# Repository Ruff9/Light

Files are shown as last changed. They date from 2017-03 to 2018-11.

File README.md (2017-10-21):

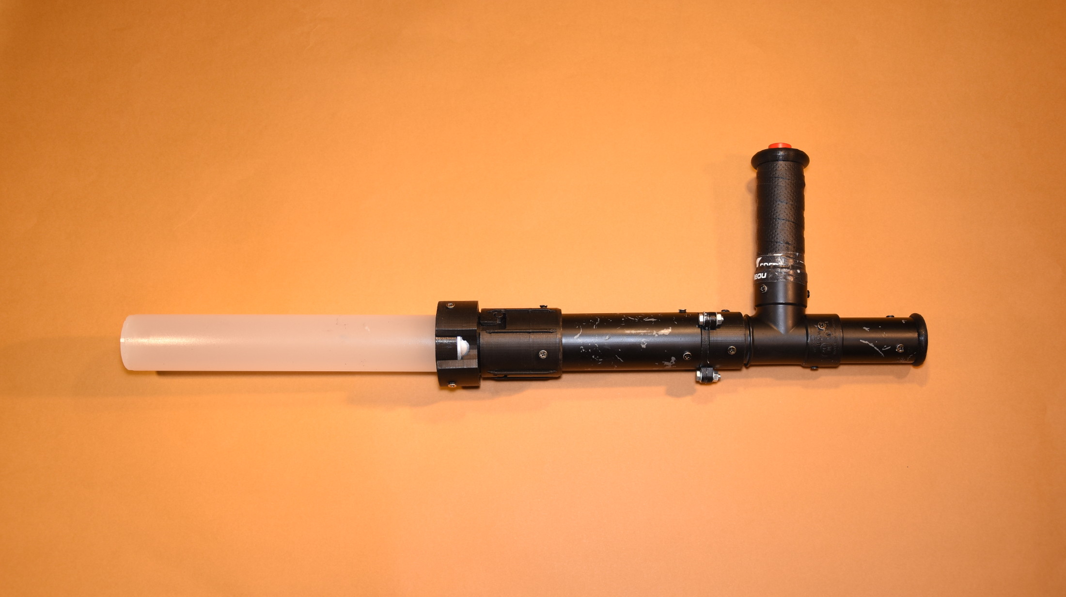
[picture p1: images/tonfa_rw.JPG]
tonfa


# Light Tonfa

Projet réalisé avec [OpenScad](http://www.openscad.org/) au FabLab du [Carrefour Numérique](http://carrefour-numerique.cite-sciences.fr/fablab/wiki/doku.php?_ga=1.200240622.1982442383.1430227391).

Ce repo contient les fichiers originaux openscad et les fichiers .stl prêts pour être chargés dans un slicer.

## Temps d'impression

Durées indicatives, correspondantes aux réglages choisis pour une Ultimaker 2. Chaque tonfa aura nécessité 32h d'impression et 1h30 d'assemblage.

- interieur: 3h
- cale_interieur: 20min
- reducteur_a: 5h30
- reducteur_b: 2h30
- embout: 2h40
- pommeau: 4h30
- cale_ampoule: 1h30
- contact_reducteur: 15min
- douille: 6h
- culot: 5h40
- ressort: 30min

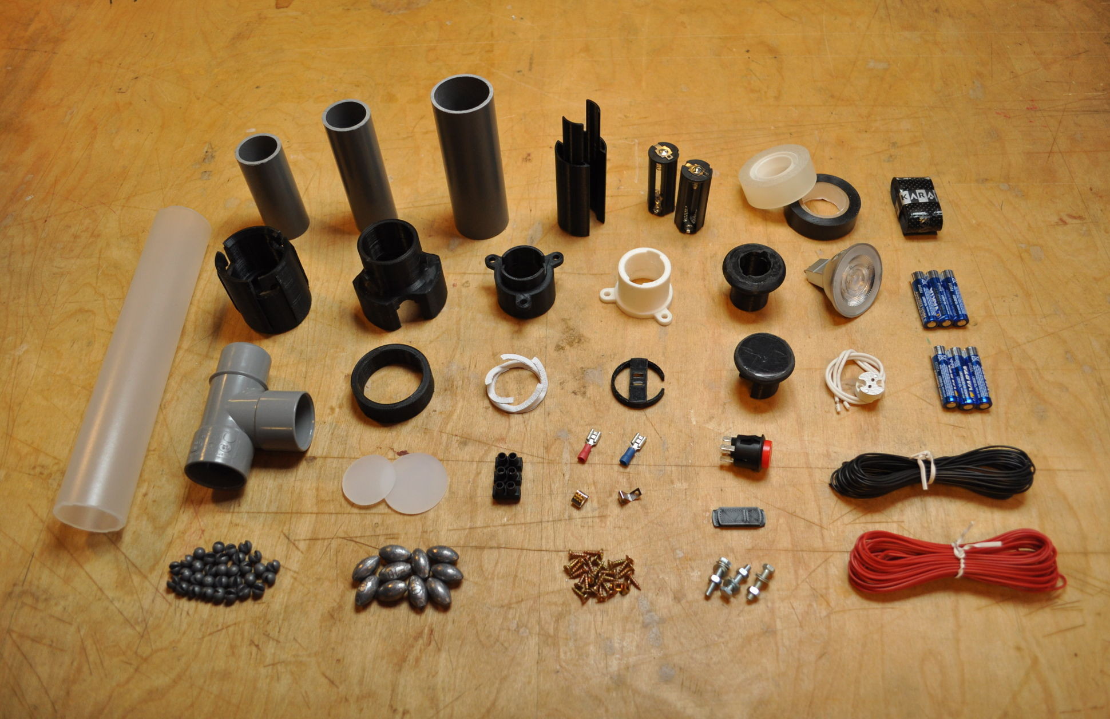
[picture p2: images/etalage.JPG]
etalage


## Autres pièces nécessaires

Tubes PVC plomberie:

- Diamètre 40mm, longueur 115 mm
- Diamètre 32mm, longueur 75mm
- Diamètre 32mm, longueur 100mm

Tube PVC translucide:

- Diamètre 40mm, longueur 230mm

Electronique

- Bouton poussoir
- 2 cosses
- 2 contacteurs
- 2 supports pour 3 piles AAA
- Domino
- Câbles

Autres:

- Raccord de plomberie en T diamètre 32mm
- Spot d'ameublement + connectique
- Rondelle de PVC translucide, diamètre 40mm
- 6 piles AAA
- 165 grammes de plombs de peche
- Sur-grip de raquette de tennis
- 24 vis de menuiserie, diamètre 4mm
- 6 écrous + vis
- Bombe de peinture noire

## Machines / outils

- Imprimante 3D
- Micro-ponçeuse (Dremel)
- Fer à souder + étain
- Banc de scie
- Perçeuse + forêt de 3.5 mm
- Visseuse
- Découpe laser (rondelle de plexiglas)
- Tournevis
- 2 Clés plates de 7

## Todo

Notice d'assemblage, wiki

## Licence

Ces fichiers sont distribués sous la licence [Creative Commons Attribution-Partage 3.0](https://creativecommons.org/licenses/by-sa/3.0/fr/).

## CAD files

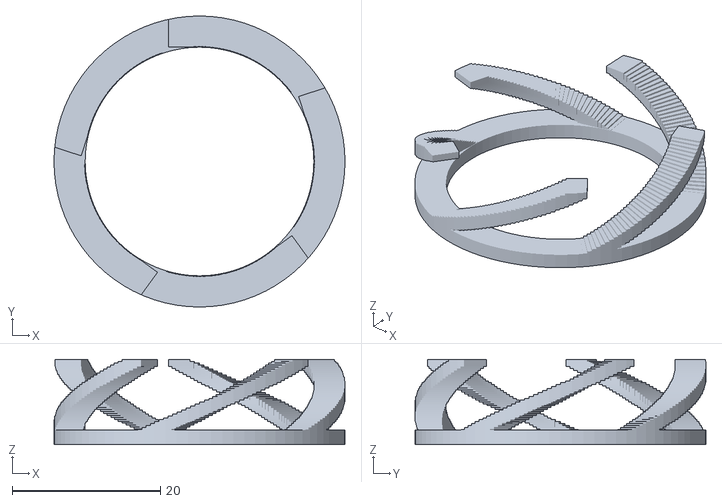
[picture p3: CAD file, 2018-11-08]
stl/ressort.stl
39.2 x 39.2 x 11.5

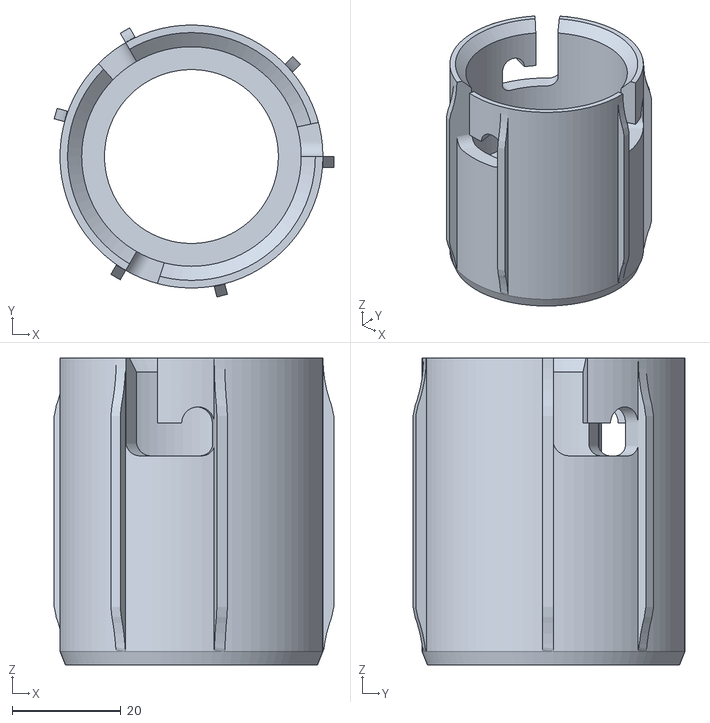
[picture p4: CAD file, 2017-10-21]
stl/douille.stl
51.5 x 50.1 x 56.5

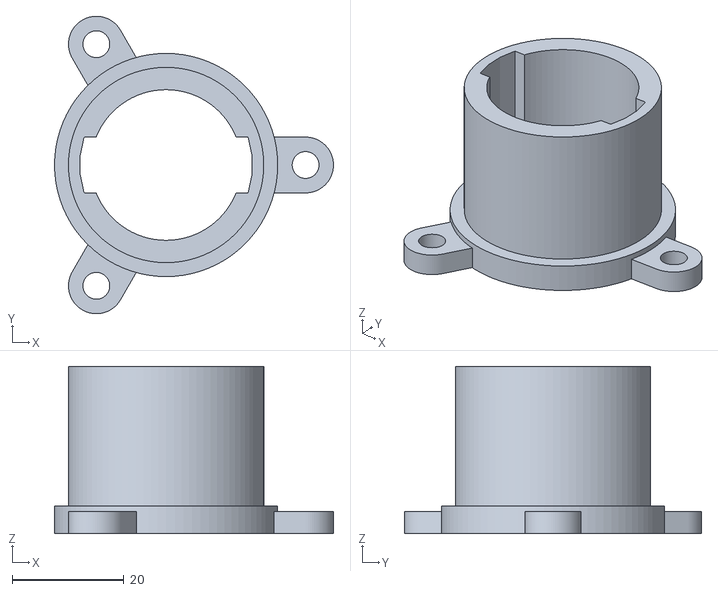
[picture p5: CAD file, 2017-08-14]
stl/reducteur_B.stl
50.0 x 53.3 x 30.0

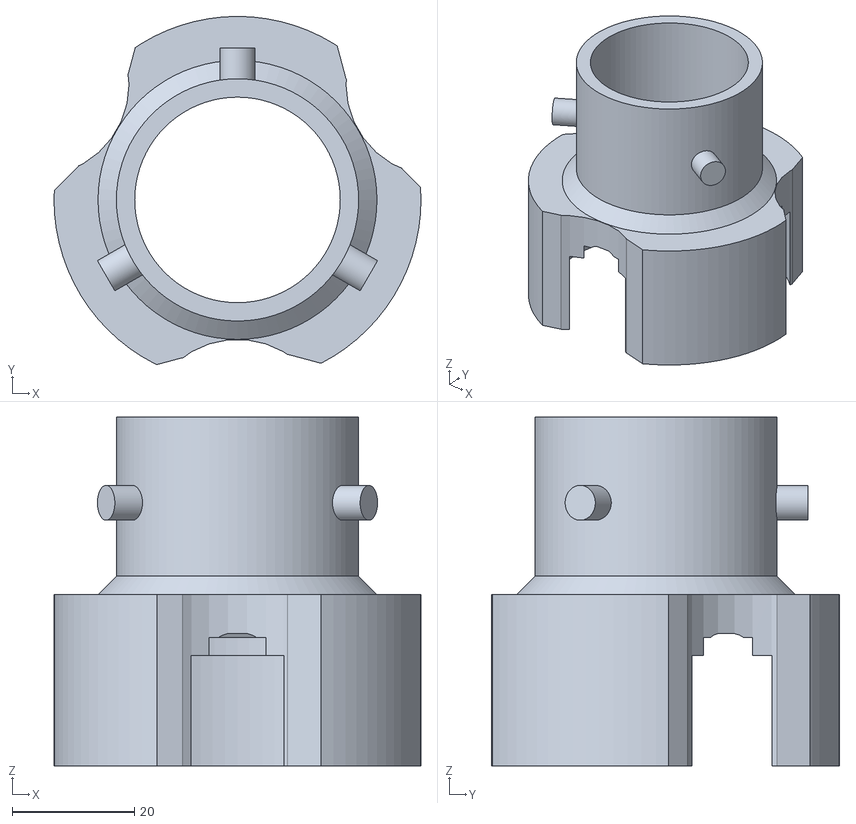
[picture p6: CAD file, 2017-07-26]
stl/culot.stl
60.0 x 56.9 x 57.0

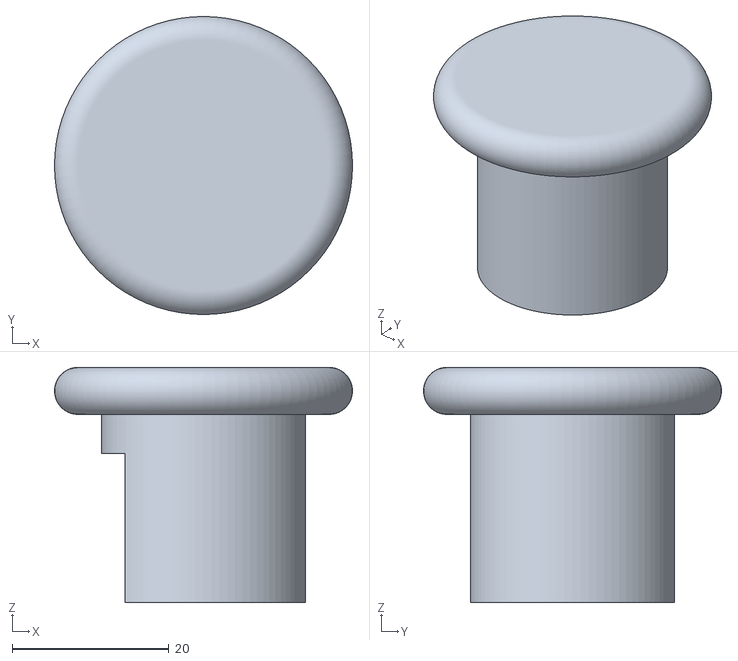
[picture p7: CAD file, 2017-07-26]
stl/embout.stl
38.0 x 38.0 x 30.0

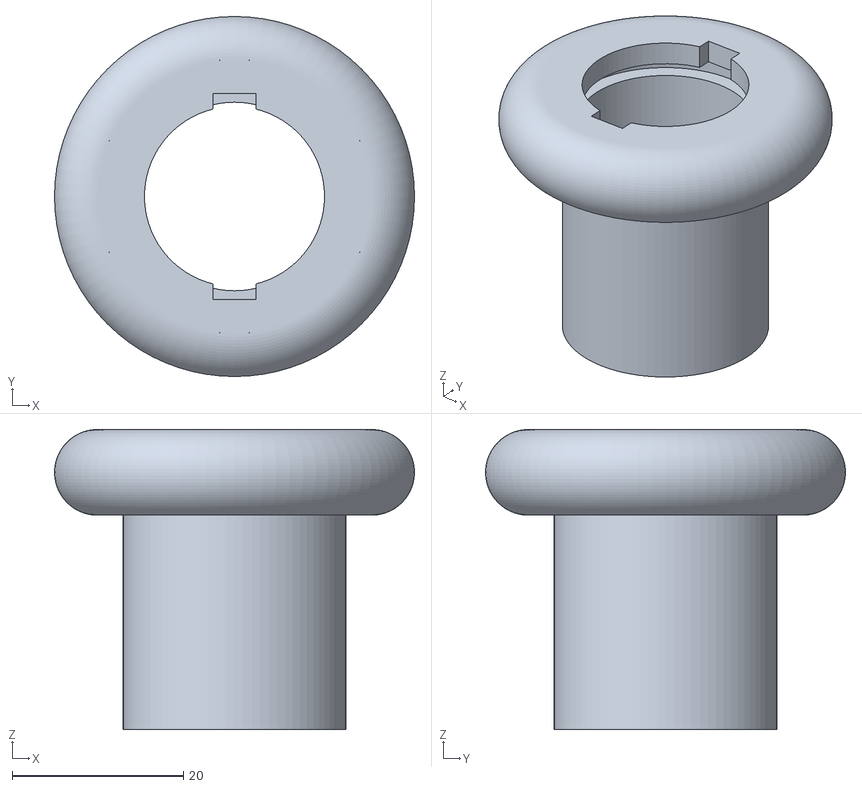
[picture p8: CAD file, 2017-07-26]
stl/pommeau.stl
42.0 x 42.0 x 35.0

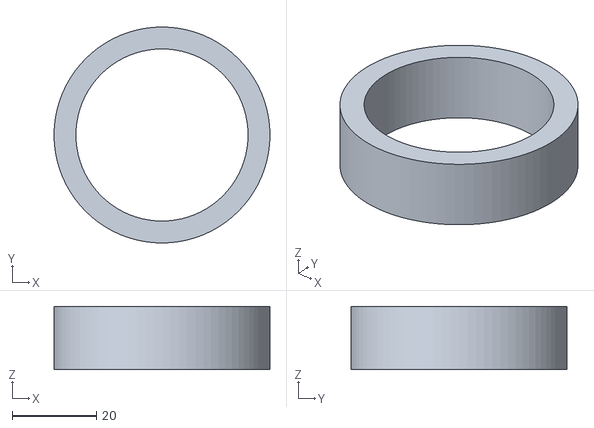
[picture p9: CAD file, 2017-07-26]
stl/cale_ampoule.stl
51.2 x 51.2 x 15.0

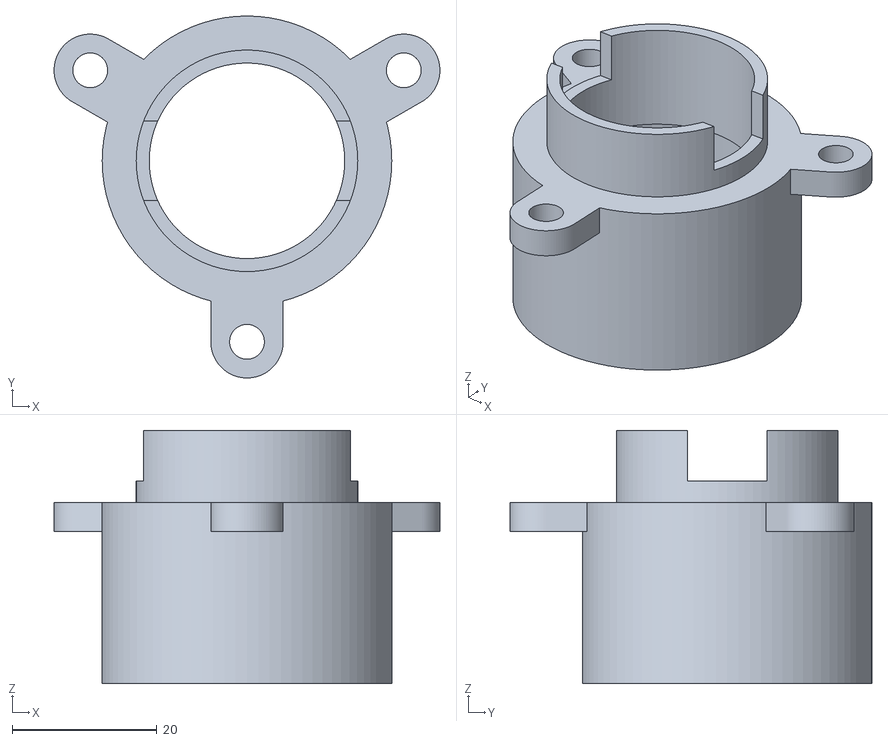
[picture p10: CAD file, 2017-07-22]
stl/reducteur_A.stl
53.3 x 50.0 x 35.0

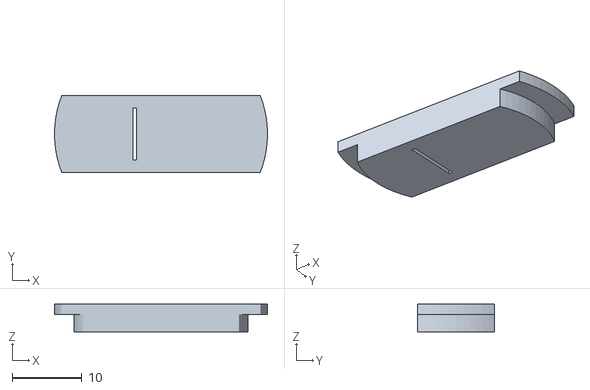
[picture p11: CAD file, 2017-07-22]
stl/contact_reducteur.stl
30.6 x 11.0 x 4.00

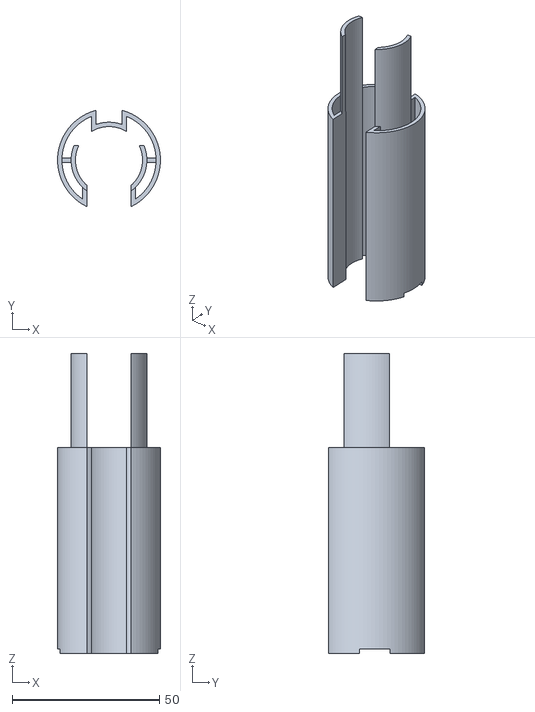
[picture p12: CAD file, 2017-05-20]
stl/interieur.stl
35.0 x 32.7 x 102.0

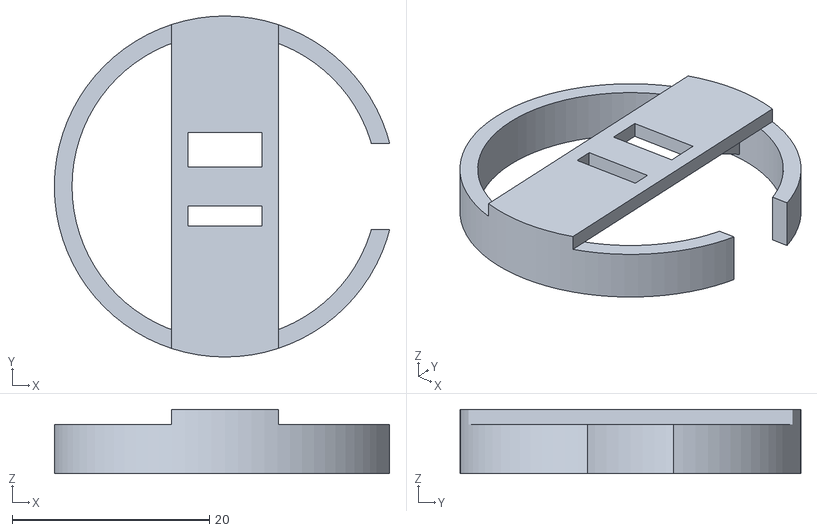
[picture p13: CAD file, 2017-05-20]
stl/cale_interieur.stl
34.0 x 34.6 x 6.50

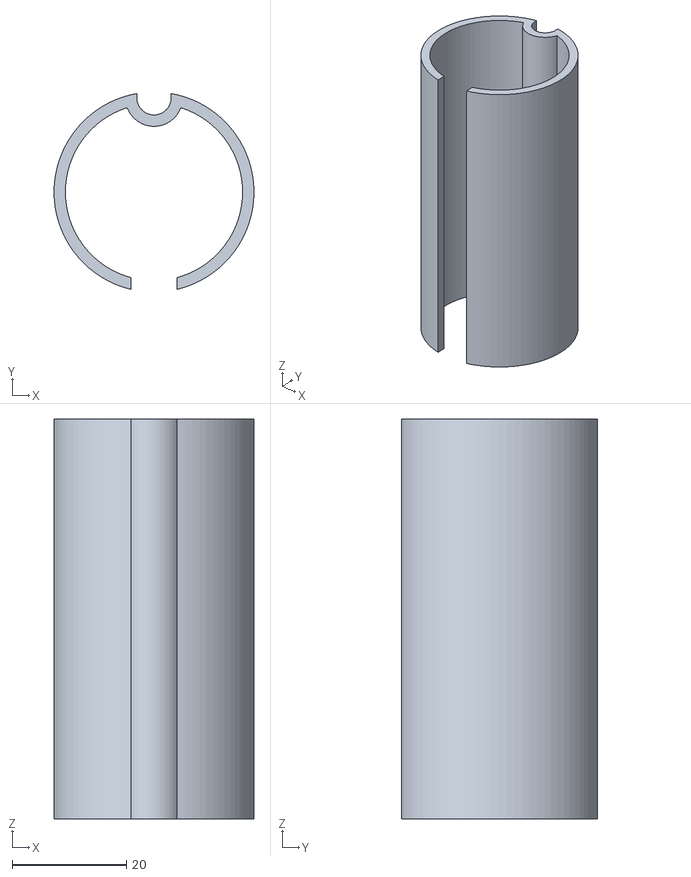
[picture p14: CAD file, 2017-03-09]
stl/gaine_cables.stl
35.0 x 34.3 x 70.0

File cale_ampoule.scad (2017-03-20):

include <common.scad>;
include <variables.scad>;

tube(15, rayon_ext_spot - delta*2, ret40 + delta*2);

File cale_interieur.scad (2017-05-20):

include <common.scad>;
include <variables.scad>;

h_cale = 5;
epaisseur = 2;

difference() {

  union() {
    tube(h_cale, rit40-delta, rit40-2, resolution);
    rotate([0,0,90]) {
      translate([0,0,h_cale])
        support_contact(rit40*2 + 2);
    }
    for ( i= [0:2] )
      rotate([0,0,i*180]) {
        equerre();
      }
  }

  translate([10,-rit40/4,-1])
    cube([rit40-10, rit40/2, h_cale+2]);
  translate([0,0,-1])
    tube(h_cale+5, rit40+2, rit40-delta);
}

module support_contact(largeur) {
  largeur_contact = 7.5;
  largeur_support = largeur_contact * 1.5 - delta*2;
  epaisseur_support = 1.5;

  difference(){
    translate([-(largeur/2)+1,-(largeur_support/2),0])
      cube([largeur-2,largeur_support,epaisseur_support]);

    translate([2,-(largeur_contact/2),-1])
      trou_contact(3.5);

    translate([0,-(largeur_contact/2),0])
      rotate([0,55,0]) {
        trou_contact(2);
      }
    translate([-4,-(largeur_contact/2),-1])
      trou_contact(2);
  }

  module trou_contact(longueur) {
    cube([longueur,largeur_contact,epaisseur_support+2]);
  }
}

module equerre() {
  translate([-2,rit40-10,0])
  difference() {
    cube([4,8,h_cale]);
    translate([-2,-3,0])
      rotate([-25,0,0]) {
        cube([8,12,h_cale]);
      }
  }
}

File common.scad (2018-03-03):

include <variables.scad>;

module tube(hauteur, rayon_exterieur, rayon_interieur, resolution=resolution) {
	difference() {
	  cylinder(hauteur, rayon_exterieur, rayon_exterieur, $fn=resolution);
	  translate([0,0,-1])
	 	  cylinder(hauteur + 2 , rayon_interieur, rayon_interieur, $fn=resolution);
	}
}

module donut(rayon_spheres, rayon_exterieur){
	rotate_extrude(convexity = 10, $fn = resolution)
		translate([rayon_exterieur,0,0])
		circle(r = rayon_spheres, $fn = resolution);
}

module languette() {
  difference(){
    union() {
      translate([5,0,0])
        cylinder(4,5,5, $fn=resolution);
      translate([-2,-5,0])
        cube([7,10,4]);
     }
    translate([5,0,-1])
      cylinder(6,2.4,2.4, $fn=resolution);
  }
}

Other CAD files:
contact_reducteur.scad
culot.scad
douille.scad
embout.scad
interieur.scad
jonction_femelle.scad
pommeau.scad
reducteurOLD.scad
reducteur_A.scad
reducteur_B.scad
ressort.scad
rondelle_ressort.scad
test_emboitement_jonction.scad
variables.scad
variables_jonction.scad

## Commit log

2015-06-13 renomme pommeau.scad
    [pommeau.scad]
2015-06-14 add embout.scad
    [common.scad, embout.scad, pommeau.scad]
2015-06-27 ajuste les variables du pommeau
    [pommeau.scad]
2015-11-07 premier passage pièce jonction
    [common.scad, embout.scad, jonction_femelle.scad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]
2015-12-19 ajoute la moitié male du fonctionnement douille
    [jonction_male.scad]
2015-12-19 premiere soustraction de matiere sur la jonction femelle
    [jonction_femelle.scad, jonction_male.scad]
2016-01-09 avancees sur la jonction femelle
    [jonction_femelle.scad]
2016-01-17 regroupement de variables pour les pièces de jonction
    [jonction_femelle.scad, jonction_male.scad, variables_jonction.scad]
2016-01-17 refactoring culot
    [jonction_femelle.scad, jonction_male.scad, variables_jonction.scad]
2016-01-19 évolution douille
    [jonction_femelle.scad, variables_jonction.scad]
2016-01-24 fait evoluer gcode
    [jonction_femelle.scad, jonction_femelle.stl, jonction_male.scad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]
2016-01-30 élargi les baionnettes
    [jonction_femelle.scad, jonction_male.scad, pommeau.scad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]
2016-02-09 renomme fichiers + update Readme
    [culot.scad, douille.scad, variables_jonction.scad]
2016-02-14 refactoring culot / douille, retour à une section droite pour l'empreinte
    [culot.scad, douille.scad, variables_jonction.scad]
2016-02-16 recompile les csv souille et culot
    [culot.stl, douille.stl, jonction_femelle.stl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]
2016-03-12 ajuste les deux pieces: fait rentrer papa dans maman
    [culot.scad, douille.scad, variables_jonction.scad]
2016-04-09 nouveau fichier scad pour le support des LEDs
    [Cone_LED.scad]
2016-04-16 nettoie le code
    [Cone_LED.scad, culot.scad, douille.scad]
2016-04-16 ajoute rebord pour le cone led
    [Cone_LED.scad]
2016-04-23 preparation de l'embout
    [Cone_LED.scad, Cone_LED.stl, common.scad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]
2016-05-14 ajoute reducteur
    [Cone_LED.scad, Cone_LED.stl, reducteur.scad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]
2016-05-20 code et encode le réducteur
    [common.scad, reducteur.scad, reducteur.stl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]
2016-05-21 compile reducteur.gcode
    [variables.scad]
2016-05-24 simplifie réducteur
    [reducteur.scad]
2016-05-24 ultra réduction du réducteur
    [reducteur.scad]
2016-05-28 répare fichier douille
    [common.scad, cone_LED.scad, culot.scad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]
2016-06-30 finalisation de la jonction
    [cale_batterie.scad, culot.scad, culot.stl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]
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2016-07-09 ajout des supports sur la rondelle ressort
    [rondelle_ressort.scad]
2016-08-07 retravail cone led + rondelle ressort
    [Cone_LED.stl, cale_chargeur.scad, cone_LED.scad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]
2016-08-21 suite du travail sur la rondelle ressort
    [cale_chargeur.stl, cale_chargeur2.scad, cale_chargeur2.stl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]
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2017-02-14 met à jour dimensions cale chargeur
    [cale_chargeur.scad, cale_chargeur.stl]
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2017-02-14 renforce un point faible de la douille
    [douille.scad, douille.stl]
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2017-03-10 met en place un support de pile depuis un fichier vendor
    [support_piles.stl]
2017-03-10 nouveau ressort + raide
    [ressort.scad, ressort.stl]
2017-03-10 ajustement jonction pour nouveau spot
    [common.scad, culot.scad, culot.stl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]
2017-03-12 corrige pb dimensions culot
    [culot.scad]
2017-03-14 créée les fichiers d'impression du culot
    [culot.stl]
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2017-03-14 supprime cone led, piece inutilisée
    [cone_LED.scad, cone_LED.stl]
2017-03-15 modifie culot, répare la jonction
    [culot.scad, culot.stl]
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2017-03-19 premiet jet reducteur en deux parties
    [reducteur.scad, reducteur.stl, reducteurOLD.scad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]
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2017-03-20 supprime les fichiers du support_piles, remplacé par une piece achetée
    [support_piles.stl]
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2017-03-22 ajout d'un contact sur le reducteur A
    [common.scad, reducteur_A.scad, reducteur_A.stl]
2017-03-22 supprime piece cale chargeur
    [cale_chargeur.scad, cale_chargeur.stl]
2017-03-22 ajout de trous de passage dans le reducteur B
    [reducteur_B.scad, reducteur_B.stl]
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2017-04-14 nouveau design ajouré pour le culot
    [culot.scad, culot.stl, variables.scad]
2017-04-15 supprime les fichioer gcode du repo
    [cale_interieur.stl, culot.scad]
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2017-04-15 réduit une variable sur le culot
    [variables.scad]
2017-04-18 ajoute une rigole pour les cables dans le réducteur B
    [reducteur_B.scad, reducteur_B.stl]
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2017-04-29 ajoute renfort sur interieur
    [interieur.scad, interieur.stl]
2017-04-29 reduit le temps d impression du culot
    [culot.scad, culot.stl]
2017-04-29 nouveau rendu reducteur A
    [reducteur_A.stl]
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2017-05-20 ajustements interieur plus cale
    [cale_interieur.scad, cale_interieur.stl, interieur.scad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]
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2017-06-04 facilite le montage du réducteur
    [reducteur_B.scad, reducteur_B.stl]
2017-07-22 renforce le contact reducteur
    [contact_reducteur.scad, contact_reducteur.stl]
2017-07-22 ajuste le reducteur A
    [reducteur_A.scad, reducteur_A.stl]
2017-07-26 ajuste stl pour production
    [cale_ampoule.stl, embout.stl, pommeau.stl]
2017-07-26 ultime renfort sur le culot
    [culot.scad, culot.stl, douille.scad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]
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2017-08-14 recentrage passage cables reducteur_b
    [reducteur_B.scad, reducteur_B.stl]
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
